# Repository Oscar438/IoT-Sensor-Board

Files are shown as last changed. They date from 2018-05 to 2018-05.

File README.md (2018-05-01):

# IoT-Sensor-Board

Eagle uses project files, these are kind of like eagle specific folders where it stores boards and schematics. To use the Git repo you'll want
to add the directory to your eagle path. Go to options>directories and add the gitlibrary folder, and project folder by pasting the path. You 
can add multiple paths by using the semicolon (;)

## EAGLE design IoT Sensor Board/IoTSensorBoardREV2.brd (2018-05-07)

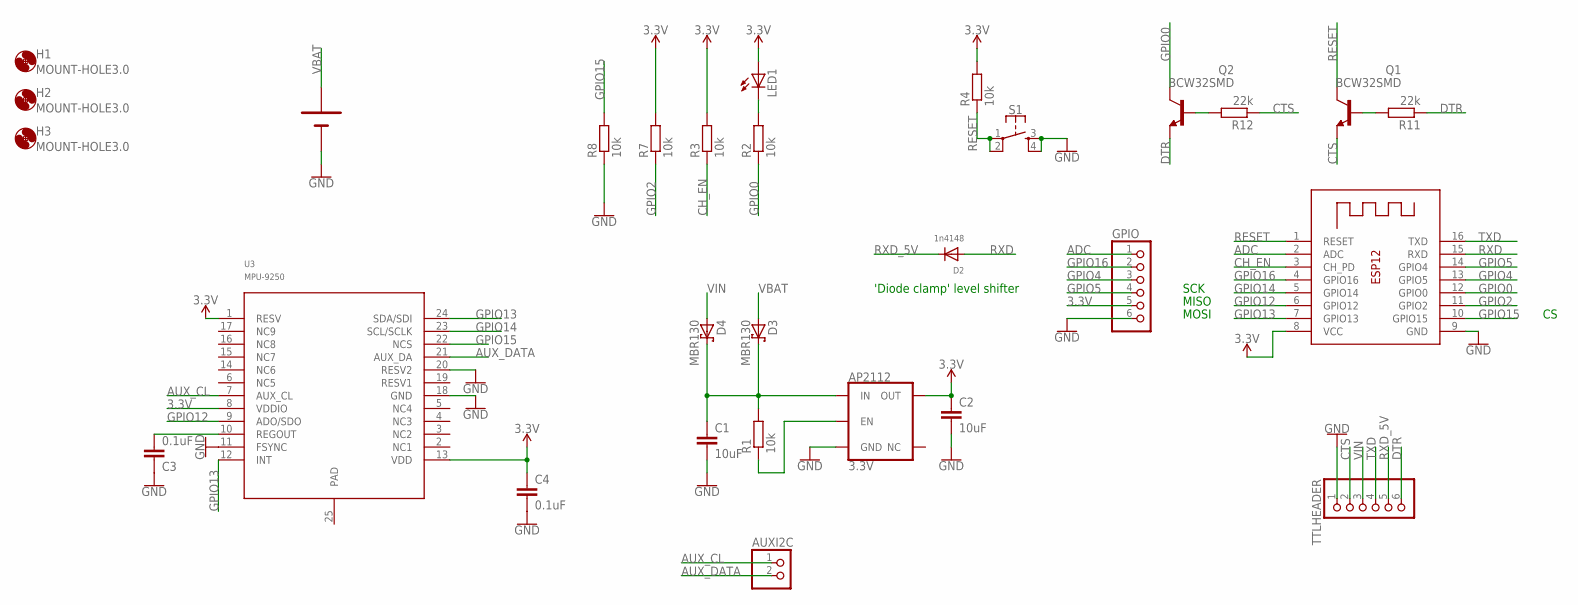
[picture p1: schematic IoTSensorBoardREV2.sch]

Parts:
AP2112: 3.3V; SOT23-5
AUXI2C: PINHD-1X2; 1X02
C1, C2: 10uF; C0805
C3, C4: 0.1uF; C0805
D2: 1n4148; SMADIODE
D3, D4: MBR130; SMB
ESP-12: ESP-12
GPIO: PINHD-1X6; 1X06
H1, H2, H3: MOUNT-HOLE3.0; 3,0
LED1: LEDCHIP-LED0805; CHIP-LED0805
Q1, Q2: BCW32SMD; SOT23-BEC
R1, R2, R3, R4, R7, R8: 10k; R0805
R11, R12: 22k; R0805
S1: MOMENTARY-SWITCH-SPST-2-SMD-5.2MM; TACTILE_SWITCH_SMD_5.2MM
TTLHEADER: PINHD-1X6; 1X06
U3: MPU-9250; LEAD-QFN24
U$1: SMTU_2450N

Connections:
3.3V: AP2112.5 (OUT), C2.1, C4.1, ESP-12.8 (VCC), GPIO.5, LED1.A, R3.2, R4.2, R7.2, U3.1 (RESV), U3.8 (VDDIO), U3.13 (VDD)
ADC: ESP-12.2 (ADC), GPIO.1
AUX_CL: AUXI2C.1, U3.7 (AUX_CL)
AUX_DATA: AUXI2C.2, U3.21 (AUX_DA)
CH_EN: ESP-12.3 (CH_PD), R3.1
CTS: Q1.E, R12.1, TTLHEADER.2
DTR: Q2.E, R11.1, TTLHEADER.6
GND: AP2112.2 (GND), C1.2, C2.2, C3.1, C4.2, ESP-12.9 (GND), GPIO.6, R8.1, S1.3, S1.4, TTLHEADER.1, U3.11 (FSYNC), U3.18 (GND), U3.20 (RESV2), U$1.P$1 (P$1N)
GPIO0: ESP-12.12 (GPIO0), Q2.C, R2.1
GPIO2: ESP-12.11 (GPIO2), R7.1
GPIO4: ESP-12.13 (GPIO5), GPIO.3
GPIO5: ESP-12.14 (GPIO4), GPIO.4
GPIO12: ESP-12.6 (GPIO12), U3.9 (ADO/SDO)
GPIO13: ESP-12.7 (GPIO13), U3.12 (INT), U3.24 (SDA/SDI)
GPIO14: ESP-12.5 (GPIO14), U3.23 (SCL/SCLK)
GPIO15: ESP-12.10 (GPIO15), R8.2, U3.22 (NCS)
GPIO16: ESP-12.4 (GPIO16), GPIO.2
unnamed: AP2112.3 (EN), R1.1
unnamed: AP2112.1 (IN), C1.1, D3.C, D4.C, R1.2
unnamed: LED1.C, R2.2
unnamed: C3.2, U3.10 (REGOUT)
unnamed: Q2.B, R12.2
unnamed: Q1.B, R11.2
RESET: ESP-12.1 (RESET), Q1.C, R4.1, S1.1, S1.2
RXD: D2.A, ESP-12.15 (RXD)
RXD_5V: D2.C, TTLHEADER.5
TXD: ESP-12.16 (TXD), TTLHEADER.4
VBAT: D3.A, U$1.P$2 (P$2P)
VIN: D4.A, TTLHEADER.3

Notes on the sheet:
'Diode clamp' level shifter
SCK
MISO
MOSI

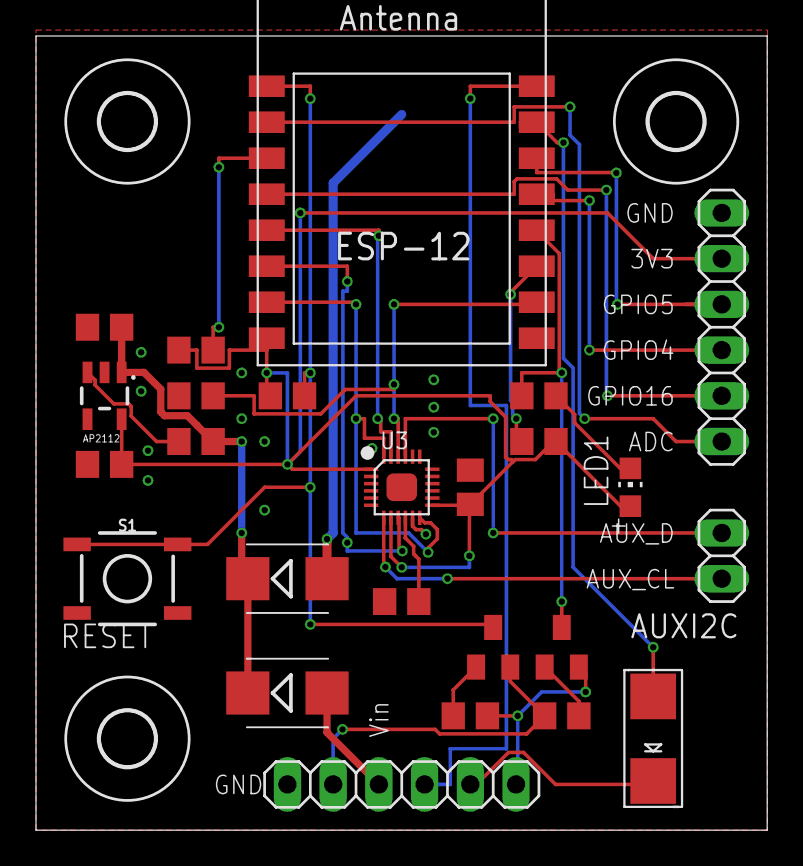
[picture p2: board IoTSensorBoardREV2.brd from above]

Board: 2 copper layers, 40.6 x 44.1 mm, 29 parts (1 on the bottom side), 29 nets.

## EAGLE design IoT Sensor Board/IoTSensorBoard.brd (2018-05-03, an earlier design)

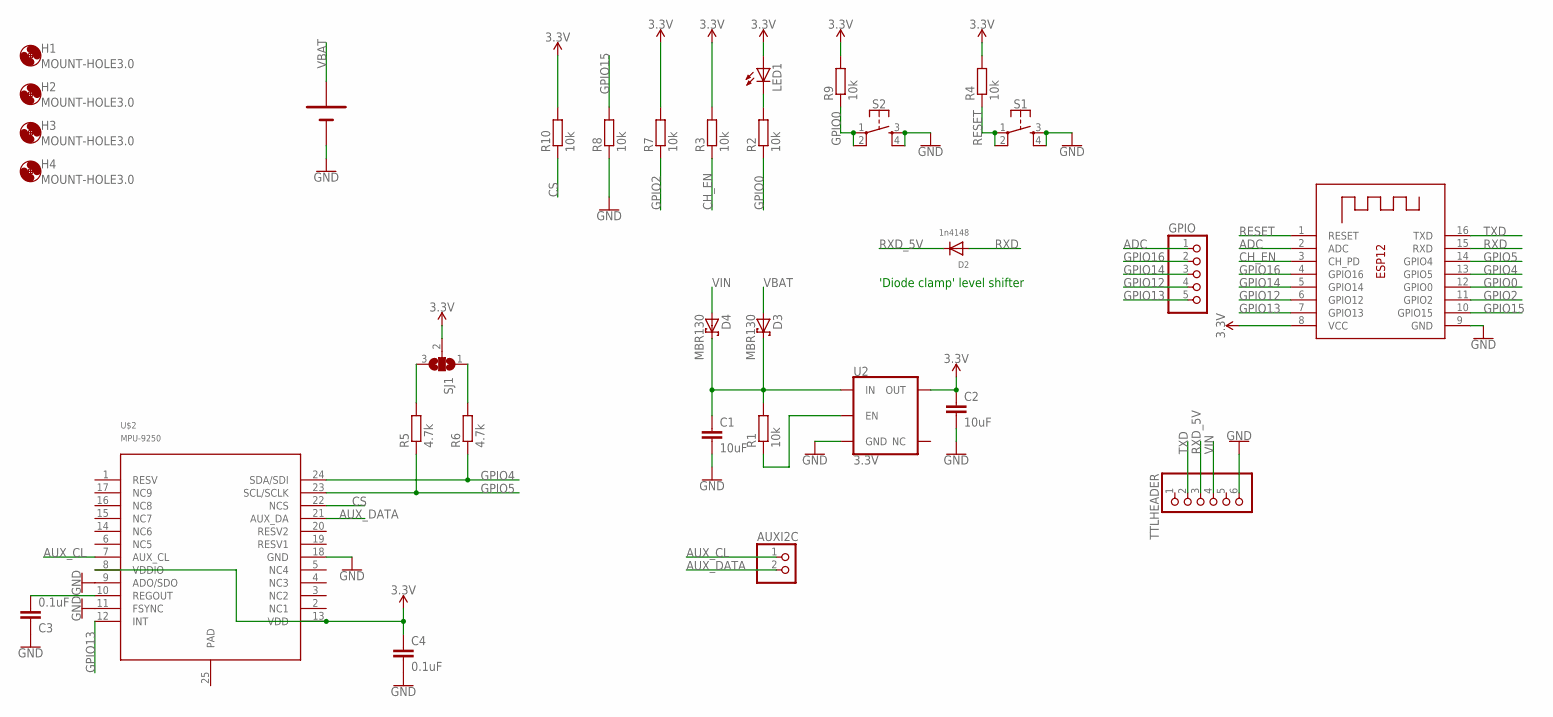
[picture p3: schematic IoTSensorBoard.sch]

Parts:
AUXI2C: PINHD-1X2; 1X02
C1, C2: 10uF; C0805
C3, C4: 0.1uF; C0805
D2: 1n4148; SMADIODE
D3, D4: MBR130; SMB
GPIO: PINHD-1X5; 1X05
H1, H2, H3, H4: MOUNT-HOLE3.0; 3,0
LED1: LEDCHIP-LED0805; CHIP-LED0805
R1, R2, R3, R4, R7, R8, R9, R10: 10k; R0805
R5, R6: 4.7k; R0805
S1, S2: MOMENTARY-SWITCH-SPST-2-SMD-5.2MM; TACTILE_SWITCH_SMD_5.2MM
SJ1: SJ2W; SJ_2
TTLHEADER: PINHD-1X6; 1X06
U2: 3.3V; SOT23-5
U$1: SMTU_2450N
U$2: MPU-9250; LEAD-QFN24
X1: ESP-12

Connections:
3.3V: C2.1, C4.1, LED1.A, R3.2, R4.2, R7.2, R9.2, R10.2, SJ1.2, U2.5 (OUT), U$2.8 (VDDIO), U$2.13 (VDD), X1.8 (VCC)
ADC: GPIO.1, X1.2 (ADC)
AUX_CL: AUXI2C.1, U$2.7 (AUX_CL)
AUX_DATA: AUXI2C.2, U$2.21 (AUX_DA)
CH_EN: R3.1, X1.3 (CH_PD)
CS: R10.1, U$2.22 (NCS)
GND: C1.2, C2.2, C3.1, C4.2, R8.1, S1.3, S1.4, S2.3, S2.4, TTLHEADER.6, U2.2 (GND), U$1.P$1 (P$1N), U$2.9 (ADO/SDO), U$2.11 (FSYNC), U$2.18 (GND), X1.9 (GND)
GPIO0: R2.1, R9.1, S2.1, S2.2, X1.12 (GPIO0)
GPIO2: R7.1, X1.11 (GPIO2)
GPIO4: R6.1, U$2.24 (SDA/SDI), X1.13 (GPIO5)
GPIO5: R5.1, U$2.23 (SCL/SCLK), X1.14 (GPIO4)
GPIO12: GPIO.4, X1.6 (GPIO12)
GPIO13: GPIO.5, U$2.12 (INT), X1.7 (GPIO13)
GPIO14: GPIO.3, X1.5 (GPIO14)
GPIO15: R8.2, X1.10 (GPIO15)
GPIO16: GPIO.2, X1.4 (GPIO16)
unnamed: R1.1, U2.3 (EN)
unnamed: C1.1, D3.C, D4.C, R1.2, U2.1 (IN)
unnamed: LED1.C, R2.2
unnamed: R5.2, SJ1.3
unnamed: C3.2, U$2.10 (REGOUT)
unnamed: R6.2, SJ1.1
RESET: R4.1, S1.1, S1.2, X1.1 (RESET)
RXD: D2.A, X1.15 (RXD)
RXD_5V: D2.C, TTLHEADER.3
TXD: TTLHEADER.2, X1.16 (TXD)
VBAT: D3.A, U$1.P$2 (P$2P)
VIN: D4.A, TTLHEADER.4

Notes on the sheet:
'Diode clamp' level shifter

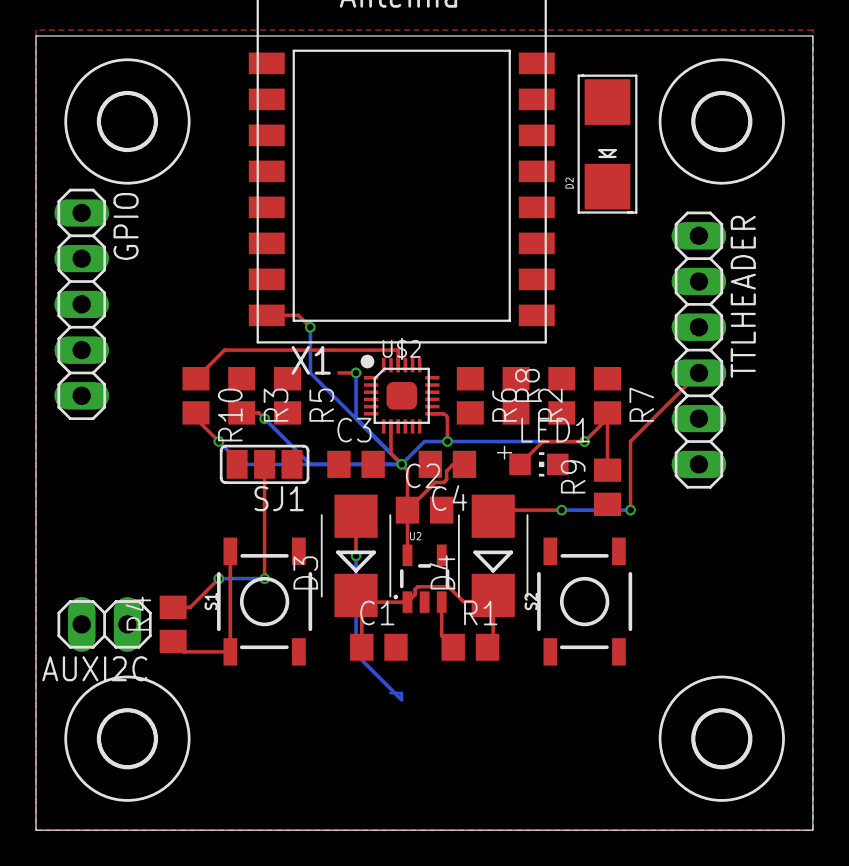
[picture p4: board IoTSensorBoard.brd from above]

Board: 2 copper layers, 43.2 x 44.1 mm, 32 parts (1 on the bottom side), 28 nets.

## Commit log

2018-05-01 ESP8266 board mostly done schematic wise
    [IoTSensorSchematic.sch]
2018-05-02 Alain Testing Git
    Added a rubbish .brd file
    [IoTSensorSchematic.brd]
2018-05-03 Schematic completed
    I had to change the MPU part, the sparkfun version had a chip that wouldn't play nice on the PCB
    [IoTSensorSchematic.brd, IoTSensorSchematic.sch]
2018-05-03 ??
    ??
    [IoTSensorSchematic.sch]
2018-05-05 Revision 2
    Revision 2 Changes:
    MPU-9250 now communicates using SPI
    Addition of two transistors to make use of FDTI breakout board DTR (Data Terminal Ready), and CTS (Clear To Send) pins. Now when programming with an FDTI adaptor the ESP-12s will automaticall reboot in programming mode.
    Removed Programming button as it's no longer needed.
    Still needs silkscreen title, and vscores
    [IoTSensorBoardREV2.brd, IoTSensorBoardREV2.sch]
2018-05-07 Updated REV2
    Silkscreen improved
    [IoTSensorBoardREV2.brd, IoTSensorBoardREV2.sch]

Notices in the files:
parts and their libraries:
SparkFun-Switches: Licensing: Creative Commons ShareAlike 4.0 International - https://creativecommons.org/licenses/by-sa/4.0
